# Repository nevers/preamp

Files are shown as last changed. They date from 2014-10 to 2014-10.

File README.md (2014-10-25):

The Preamp
==========

The aim of this project is to create a yet high fidelity stereo pre-amplifier. It is designed to provide comfort features such as IR remote control and an LCD display without compromising the audio quality.

Preamp front

The preamp exhibits the following features:
* Six independenly selectable stereo inputs.
* Two low noise and low distortion identical stereo outputs.
* Digitally-controlled analog volume control using a rotary encoder. 
* Wide gain and attenuation range from +31.5dB to -95.5dB with 0.5dB steps.
* An LCD showing the currently selected channel and its volume in dB.

All electronics and hardware, including PCB and eclosure is costum design. At the heart of system, the PIC 18F4520 microcontroller is used. It controls the whole preamp: from listening to the rotary encoder and the IR inputs to selecting the active output channels and setting the output volume.

Preamp inner

The main audio path is build from high-end components such as the OPA2134, an ultra-low distortion, low noise operational amplifier. More specifically, the OPA2134 is used at the input lines of the preamp. It's high impedance input stage draws as little as 5pA (excluding the filtering stage in front of it), providing superior sound capturing for the next stage. The audio is then sent to the PGA2311, a high-quality volume controller capable of completely muting the audio and aplifying it as much as +31.5dB. It is controlled by the microcontroller using SPI in steps of 0.5dB. It also includes a zero crossing detection, allowing noise free level transitions. The final component in the audio path is the NE5532, a capable operational amplifier, selected for its excellent audio performance and its high output current, which is indespensible for driving the outputs of the preamp.

All code is available in the software folder. All schematicsm PCB design and enclosure design is available in PDF format in the hardware folder.

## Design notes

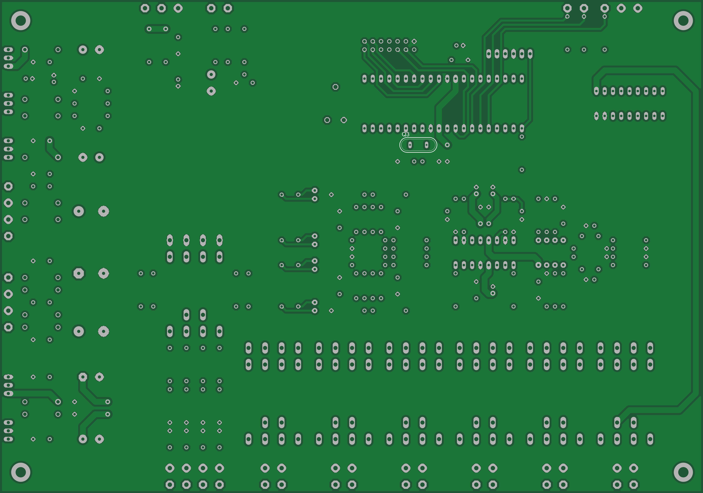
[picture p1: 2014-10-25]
hardware/preamp-board-bottom.png

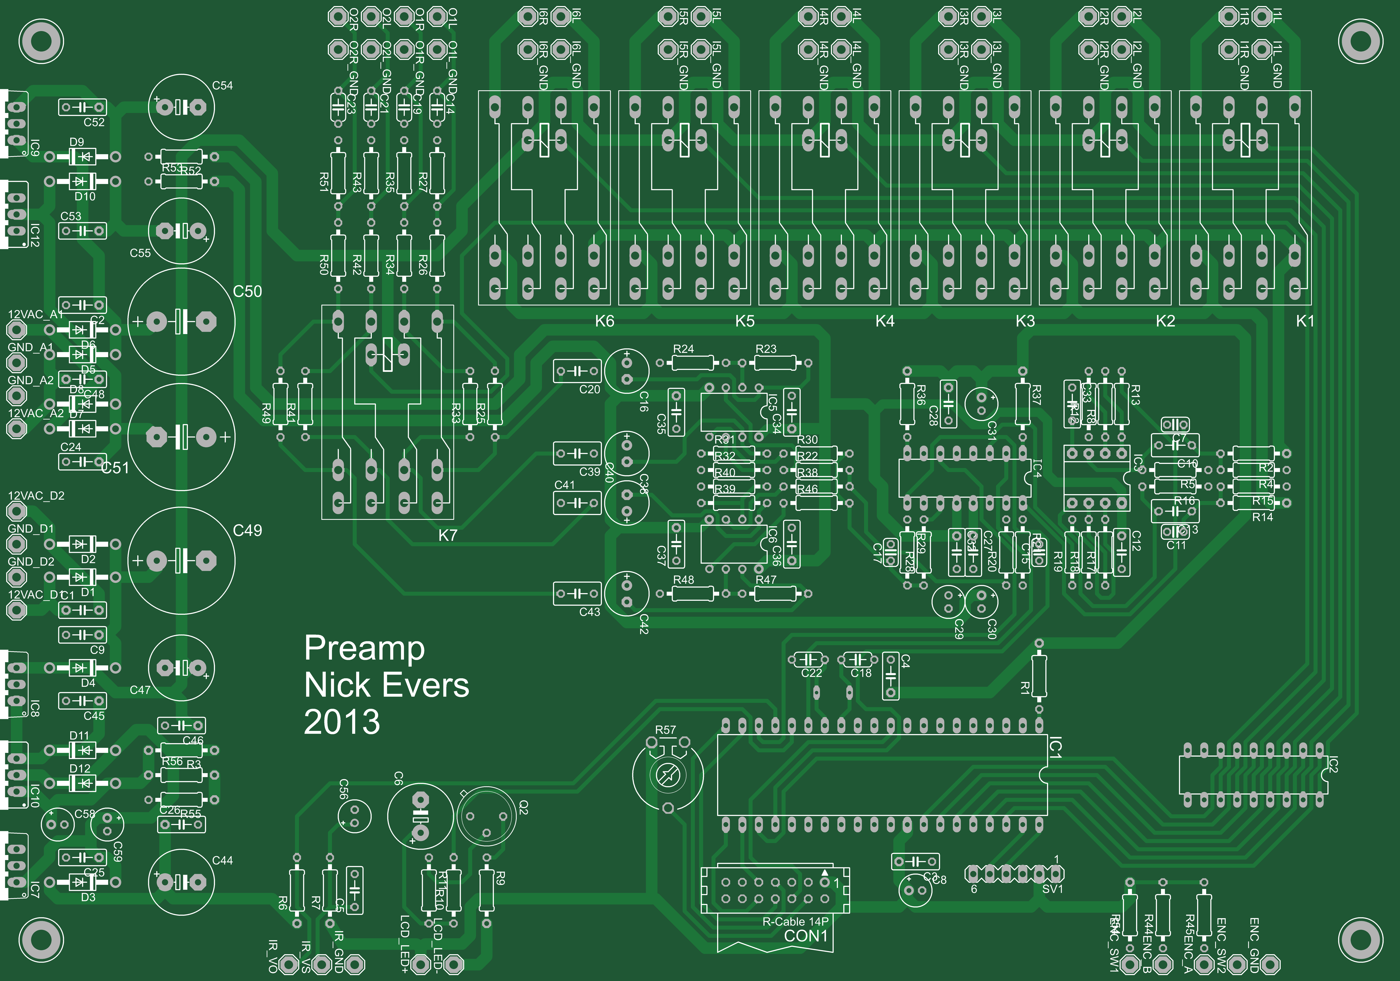
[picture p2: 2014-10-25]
hardware/preamp-board-top.png

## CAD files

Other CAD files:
hardware/preamp-enclosure.skp

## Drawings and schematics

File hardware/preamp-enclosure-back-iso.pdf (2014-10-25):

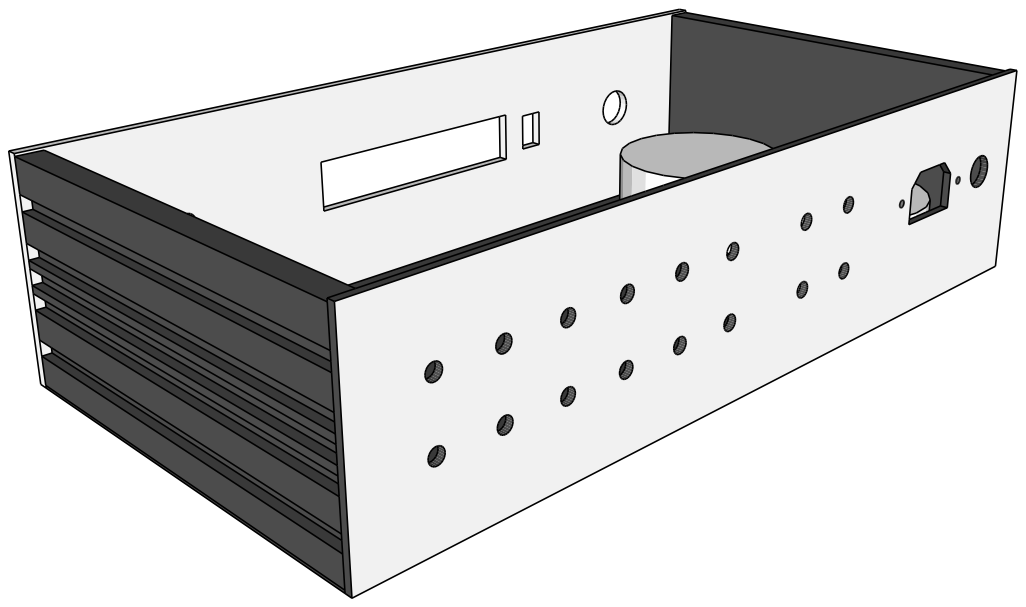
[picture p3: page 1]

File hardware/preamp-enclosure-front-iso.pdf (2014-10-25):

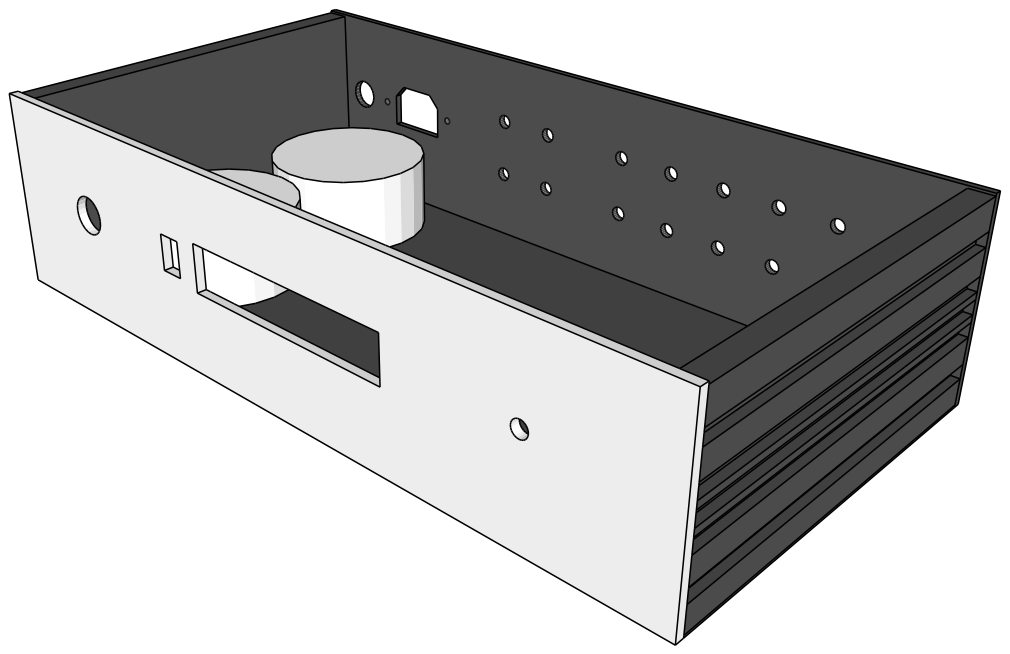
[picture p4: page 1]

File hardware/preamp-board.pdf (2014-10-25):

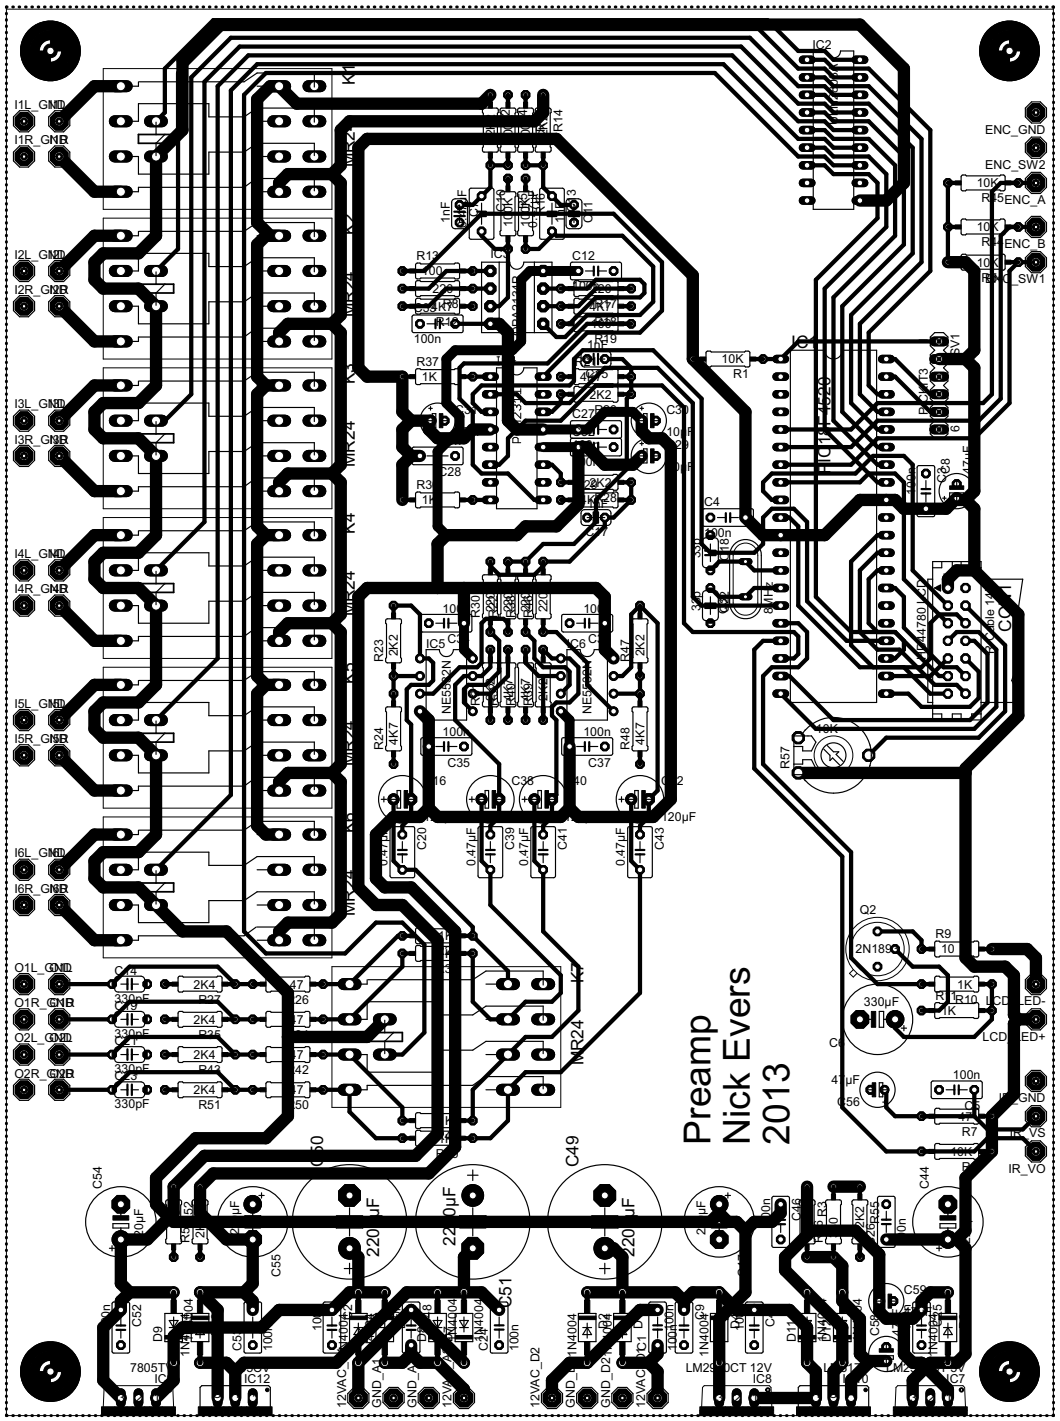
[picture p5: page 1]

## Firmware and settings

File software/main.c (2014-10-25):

#include <p18F4520.h>
#include <stdlib.h>
#include <delays.h>
#include <spi.h>
#include <string.h>

#include "lcd/xlcd.h"
#include "ir/ir.h"
#include "volume/volume.h"
#include "channels/channels.h"
#include "encoder/encoder.h"

void interruptHandler(void);
void init(void);
void displayCredits(void);
void checkDecodedIRCommands(void);
void checkEncoderState(void);
void updateDisplay(void);
void clearDisplay(void);
void displayAudioChannel(void);
void displayVolumeInDB(void);
void displayVolumeInBars(void);

#pragma config OSC = HS
#pragma config WDT = OFF
#pragma config LVP = OFF
#pragma config PWRT = OFF
#pragma config DEBUG = OFF
#pragma config BOREN = NOSLP
#pragma config BORV = 1
#pragma config IESO = OFF

#pragma code interrupt_vector = 0x08

void atInterrupt(void) {
    _asm goto interruptHandler _endasm
}

#pragma code
#pragma interrupt interruptHandler

void interruptHandler(void) {
    //An overflow occured on timer 1.
    if (PIR1bits.TMR1IF) { 
        timeoutIRBit();
        PIR1bits.TMR1IF = 0;
    }

    // An overflow occured on timer 3.
    if (PIR2bits.TMR3IF) {
        timeoutIRFrame();
        PIR2bits.TMR3IF = 0;
    }

    // An interrupt occured on CCP1 (RC2 pin)
    if (PIR1bits.CCP1IF) { 
        decodeIR();
        PIR1bits.CCP1IF = 0;
    }
}

void main(void) {
    init();
    enableBacklightXLCD();
    enableIR();
    displayCredits();
    enableMasterChannel();
    setChannel(DEFAULT_CHANNEL);
    updateDisplay();

    while (1) {
        checkDecodedIRCommands();
        checkEncoderState();
        checkBacklightXLCDTimer();
    }
}

void init(void) {
    ADCON1 = 0xff; //Set all analog pins as digital on PORTA
    CMCON = 0xff; // Disable all comparators on PORTA
    initIR();
    initXLCD();
    initVolume();
    initAudioChannels();
    initEncoder();
}

void displayCredits() {
    clearDisplay();

    while (BusyXLCD());
    putrsXLCD("       The Preamp");

    while (BusyXLCD());
    SetDDRamAddr(40); // Set cursor on second line

    Delay10KTCYx(255);

    while (BusyXLCD());
    putrsXLCD("Nick Evers   ");

    while (BusyXLCD());
    putrsXLCD(__DATE__);

    Delay10KTCYx(255);
    Delay10KTCYx(255);
    Delay10KTCYx(255);
}

void checkDecodedIRCommands() {
    if (!ir.decoded)
        return;

    if (ir.repeated && ir.command != IR_CMD_VOL_UP && ir.command != IR_CMD_VOL_DOWN)
        return;

    if (ir.address != 27526) {
        enableIR();
        return;
    }

    switch (ir.command) {
        case IR_CMD_MUTE:
            mute();
            break;
        case IR_CMD_VOL_UP:
            incrementVolume();
            break;
        case IR_CMD_VOL_DOWN:
            decrementVolume();
            break;
        case IR_CMD_CH_UP:
            incrementChannel();
            break;
        case IR_CMD_CH_DOWN:
            decrementChannel();
            break;
        case IR_CMD_1:
            setChannel(1);
            break;
        case IR_CMD_2:
            setChannel(2);
            break;
        case IR_CMD_3:
            setChannel(3);
            break;
        case IR_CMD_4:
            setChannel(4);
            break;
        case IR_CMD_5:
            setChannel(5);
            break;
        case IR_CMD_6:
            setChannel(6);
            break;
    }

    updateDisplay();
    enableIR();
}

void checkEncoderState() {
    EncoderState encoderState = getEncoderState();

    switch (encoderState) {
        case cw:
            incrementVolume();
            break;
        case ccw:
            decrementVolume();
            break;
        case pressed:
            incrementChannel();
            break;
    }

    if (encoderState != inactive)
        updateDisplay();
    clearEncoderState();
}

void updateDisplay() {
    clearDisplay();
    displayAudioChannel();
    displayVolumeInDB();
    displayVolumeInBars();
    enableBacklightXLCD();
}

void clearDisplay() {
    while (BusyXLCD());
    WriteCmdXLCD(CLEAR_DISPLAY);

    while (BusyXLCD());
    SetDDRamAddr(0);
}

void displayAudioChannel() {
    char buffer[] = " ";

    while (BusyXLCD());
    putrsXLCD("Channel: ");

    itoa(getChannel(), buffer);
    while (BusyXLCD());
    putsXLCD(buffer);
}

void displayVolumeInDB() {
    char buffer[] = "    ";
    int volumeInDb = getVolumeInDB();

    while (BusyXLCD());
    if (volumeInDb == 0)
        SetDDRamAddr(21);
    else if (volumeInDb > 9 || volumeInDb < -9)
        SetDDRamAddr(19);
    else
        SetDDRamAddr(20);

    if (volumeInDb > 0) {
        while (BusyXLCD());
        putrsXLCD("+");
    }

    itoa(volumeInDb, buffer);
    while (BusyXLCD());
    putsXLCD(buffer);

    while (BusyXLCD());
    putrsXLCD("dB");
}

void displayVolumeInBars() {
    int volumeInBars = getVolumeInBars();
    int i;

    while (BusyXLCD());
    SetDDRamAddr(40); // Set cursor on second line

    for (i = 0; i < volumeInBars; i++) {
        while (BusyXLCD());
        putcXLCD(0xff);
    }
}

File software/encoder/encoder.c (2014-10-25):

#include "encoder.h"
#include <p18cxxx.h>
#include <delays.h>


int isEncoderAChanged(void);
int isEncoderBChanged(void);
int isEncoderButtonChanged(void);
void storeEncoders(void);

EncoderState encoderState = inactive;

int encoderA = 0;
int encoderB = 0;
int encoderButton = 0;
int prevEncoderA = 0;
int prevEncoderB = 0;
int prevEncoderButton = 0;

void initEncoder() {
    ENCODER_A_PIN = 1;
    ENCODER_B_PIN = 1;
    ENCODER_SW_PIN = 1;
}

void clearEncoderState() {
    encoderState = inactive;
}

EncoderState getEncoderState() {
    if (isEncoderAChanged() || isEncoderBChanged())
        if (encoderA && encoderB && !prevEncoderB)
            encoderState = ccw;
        else if (encoderA && !encoderB && prevEncoderB)
            encoderState = cw;
    if (isEncoderButtonChanged() && encoderButton)
        encoderState = pressed;
    storeEncoders();
    return encoderState;
}

int isEncoderAChanged() {
    int encoderASample1;
    int encoderASample2;

    encoderASample1 = !ENCODER_A;
    Delay10TCYx(DEBOUNCE_DELAY);
    encoderASample2 = !ENCODER_A;

    if (encoderASample1 == encoderASample2)
        encoderA = encoderASample1;
    else
        return 0;
    return encoderA != prevEncoderA;
}

int isEncoderBChanged() {
    int encoderBSample1;
    int encoderBSample2;

    encoderBSample1 = !ENCODER_B;
    Delay10TCYx(DEBOUNCE_DELAY);
    encoderBSample2 = !ENCODER_B;

    if (encoderBSample1 == encoderBSample2)
        encoderB = encoderBSample1;
    else
        return 0;
    return encoderB != prevEncoderB;
}

int isEncoderButtonChanged() {
    int encoderButtonSample1;
    int encoderButtonSample2;

    encoderButtonSample1 = !ENCODER_BUTTON;
    Delay10TCYx(DEBOUNCE_DELAY);
    encoderButtonSample2 = !ENCODER_BUTTON;

    if (encoderButtonSample1 == encoderButtonSample2)
        encoderButton = encoderButtonSample1;
    else
        return 0;
    return encoderButton != prevEncoderButton;
}

void storeEncoders() {
    prevEncoderA = encoderA;
    prevEncoderB = encoderB;
    prevEncoderButton = encoderButton;
}

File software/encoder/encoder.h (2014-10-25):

#ifndef __ENCODER_H
#define	__ENCODER_H

#define ENCODER_A_PIN  TRISAbits.RA3
#define ENCODER_B_PIN  TRISAbits.RA4
#define ENCODER_SW_PIN TRISAbits.RA5

#define ENCODER_A  PORTAbits.RA3
#define ENCODER_B  PORTAbits.RA4
#define ENCODER_BUTTON PORTAbits.RA5

#define DEBOUNCE_DELAY 50

typedef enum ENCODER_STATE {
    inactive,
    cw,
    ccw,
    pressed
} EncoderState;

void initEncoder(void);
void clearEncoderState(void);
EncoderState getEncoderState(void);

#endif
